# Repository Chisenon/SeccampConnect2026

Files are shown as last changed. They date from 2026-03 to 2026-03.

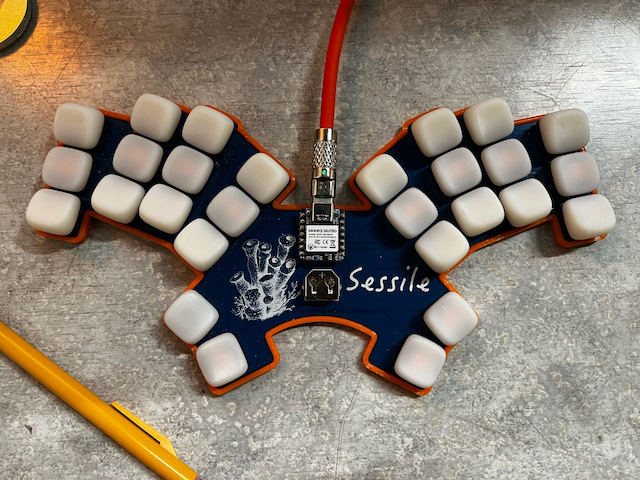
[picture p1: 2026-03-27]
rmk/docs/docs/main/images/sessile.png

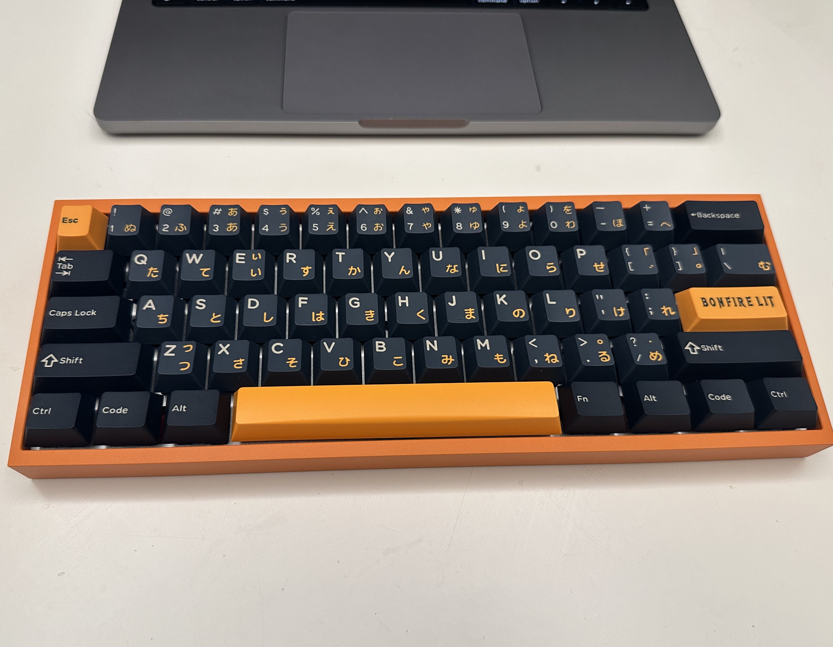
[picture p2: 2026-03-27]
rmk/docs/docs/main/images/rmk_ble_keyboard.jpg

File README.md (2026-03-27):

# SeccampConnect2026
Security Camp Connect 2026

## クイックスタート（開発・書き込み手順）

開発には Docker (ビルド用) とホスト側の `espflash` (書き込み用) を使用します。
アーキテクチャの図解やコマンドの詳細は [WORKFLOW.md](WORKFLOW.md) を参照してください。

### 1. 開発用コンテナの起動
バックグラウンドでビルド用コンテナを待機させます。
```powershell
docker compose up -d
```

### 2. ビルドの実行
起動中のコンテナ内で `cargo build` を実行します。
```powershell
docker compose exec build cargo build --release
```

### 3. デバイスを「書き込みモード」にする（重要！）
ESP32-S3に書き込むには、マイコンを**ダウンロードモード**にする必要があります。

1. マイコン基板上の **BOOTボタン** を押しっぱなしにする
2. PCにUSBケーブルを接続する（接続済みの場合は、BOOTを押しながらRESETボタンを押して離す）
3. BOOTボタンを離す

### 4. ファームウェアの書き込み
割り当てられたCOMポート（例：`COM3`）を確認して書き込みます。
```powershell
# ポート確認
Get-CimInstance Win32_SerialPort | Select-Object Name, Description

# フラッシュ（COM3の場合）
espflash flash .\target\xtensa-esp32s3-none-elf\release\SeccampConnect2026 --port COM3
```

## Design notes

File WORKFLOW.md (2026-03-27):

```mermaid
flowchart TD
    subgraph HOST["Host (Windows)"]
        EDITOR["エディタ <br> src/main.rs を編集"]
        VOLUME[".\\ (プロジェクトルート)"]
        ESPFLASH["espflash<br>(ホスト側)"]
        COM["USB Serial<br>COM3 等"]
        ESP32S3["ESP32S3<br>(XIAO) / BOOTボタンON"]
    end

    subgraph CONTAINER["Docker Container (常時起動)"]
        MOUNT["/work (bind mount)"]
        CARGO["cargo build --release<br>(Xtensa Rust toolchain esp)"]
        ELF["target/xtensa-esp32s3-none-elf <br> /release/SeccampConnect2026"]

        MOUNT --> CARGO
        CARGO --> ELF
    end

    EDITOR -->|"1. ファイル保存"| VOLUME
    VOLUME <-->|"bind mount<br>.:/work"| MOUNT
    ELF -->|"target/ はホストと共有"| VOLUME

    VOLUME -->|"2. docker compose exec build..."| CONTAINER

    VOLUME -->|"4. espflash flash ... --port COM3"| ESPFLASH
    ESPFLASH -->|"USB通信"| COM
    COM -->|"3. ダウンロードモード待機"| ESP32S3
```

## 開発ワークフロー

### 1. 開発環境の起動
DevContainerが言う事聞いてくれないから、
Dockerでビルド用コンテナを手動で起動します。
```powershell
docker compose up -d
```

### 2. ファームウェアのビルド
起動中のコンテナ内でビルドを実行します。
```powershell
docker compose exec build cargo build --release
```

### 3. デバイスを書き込みモード（ダウンロードモード）にする
**BOOTボタンを押しながら**接続してデバイスをPCに認識させる！

### 4. ポートの確認
デバイスが認識されたら、COMポート番号を確認します。
```powershell
Get-CimInstance Win32_SerialPort | Select-Object Name, Description
```

COMX の部分は、実際に認識されたCOMポート番号に置き換えてね！

```
COM3
```

### 5. ファームウェアの書き込み
ホスト側（Windows）から `espflash` を使ってビルドしたELFファイルを書き込みます。
```powershell
espflash flash .\target\xtensa-esp32s3-none-elf\release\SeccampConnect2026 --port COMX
```

---

## コマンド早見表

| ステップ | コマンド |
|---|---|
| コンテナ起動 | `docker compose up -d` |
| コンテナ停止 | `docker compose down` |
| ビルド (release) | `docker compose exec build cargo build --release` |
| ビルドシェルに入る | `docker compose exec build bash` |
| ポート確認 | `Get-CimInstance Win32_SerialPort \| Select-Object Name, Description` |
| 書き込み | `espflash flash .\target\xtensa-esp32s3-none-elf\release\SeccampConnect2026 --port COMX` |

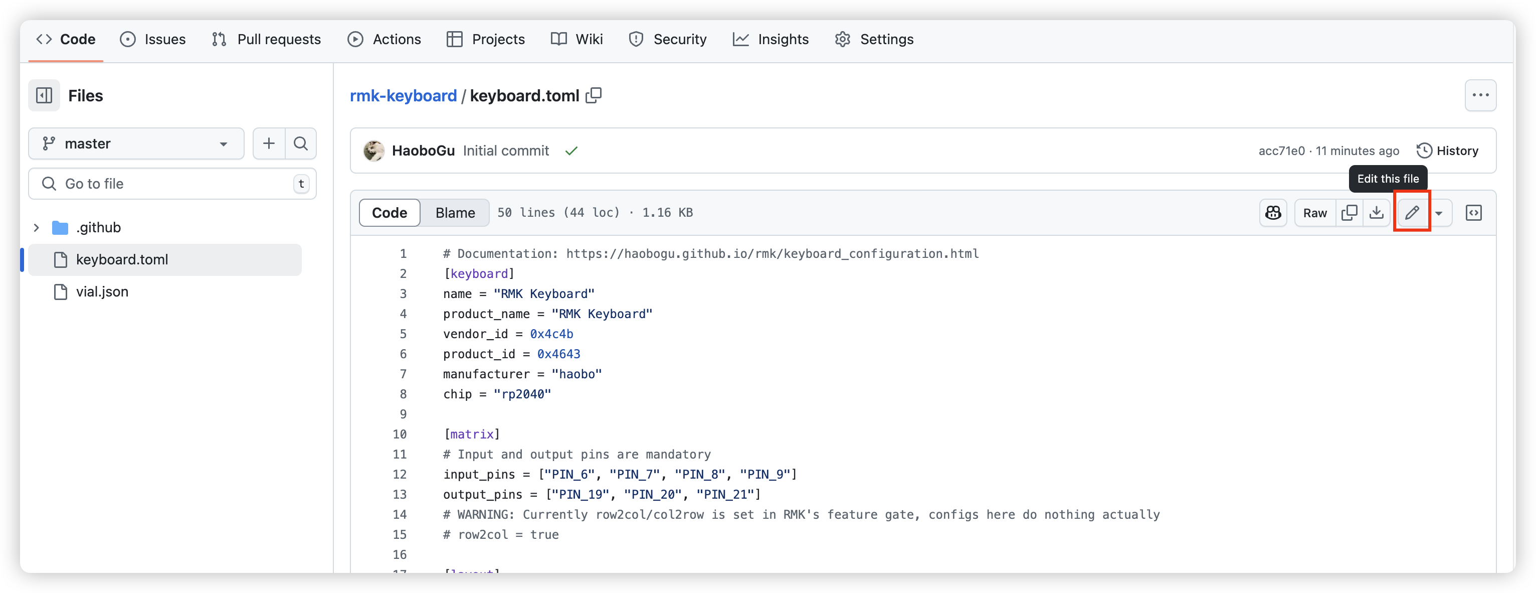
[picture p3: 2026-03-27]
rmk/docs/docs/main/images/edit_config_file.png

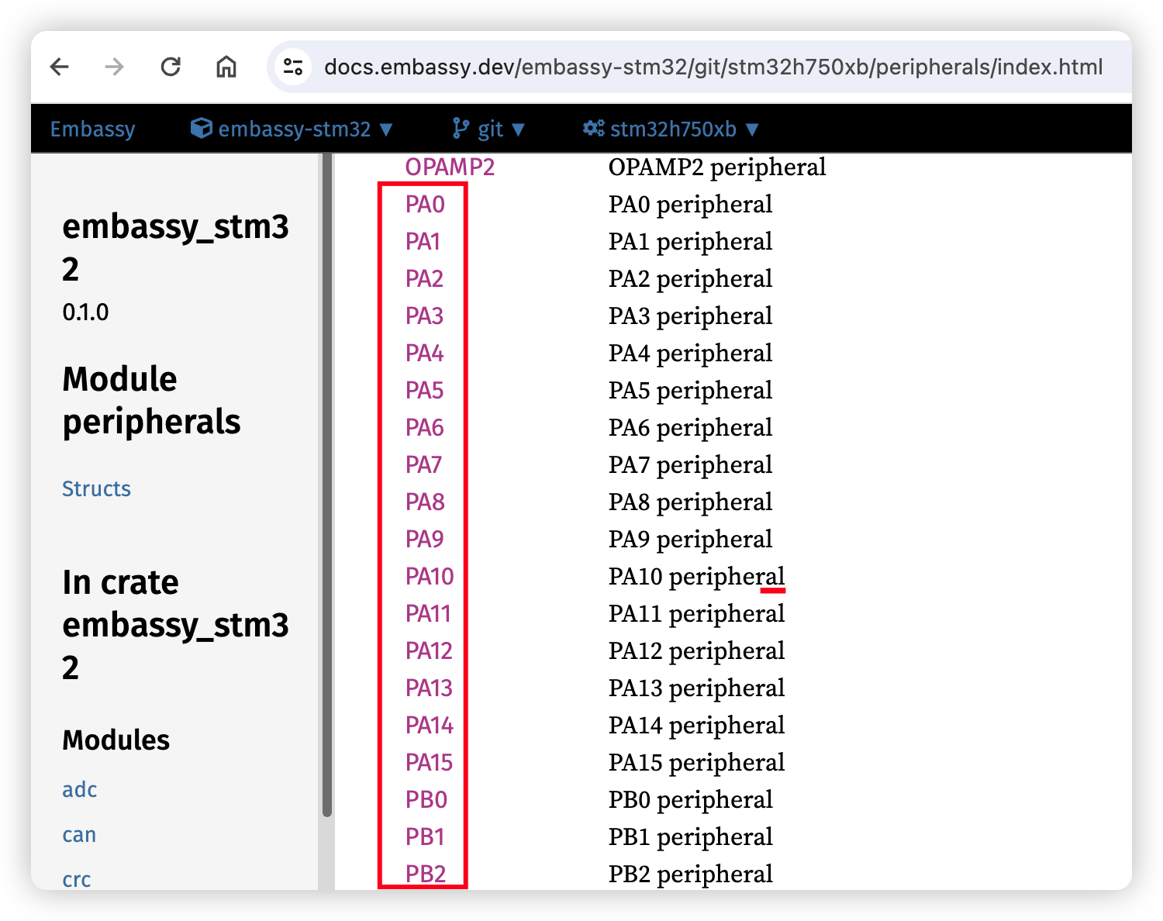
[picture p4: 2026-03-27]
rmk/docs/docs/main/images/gpio_peripheral_name.png

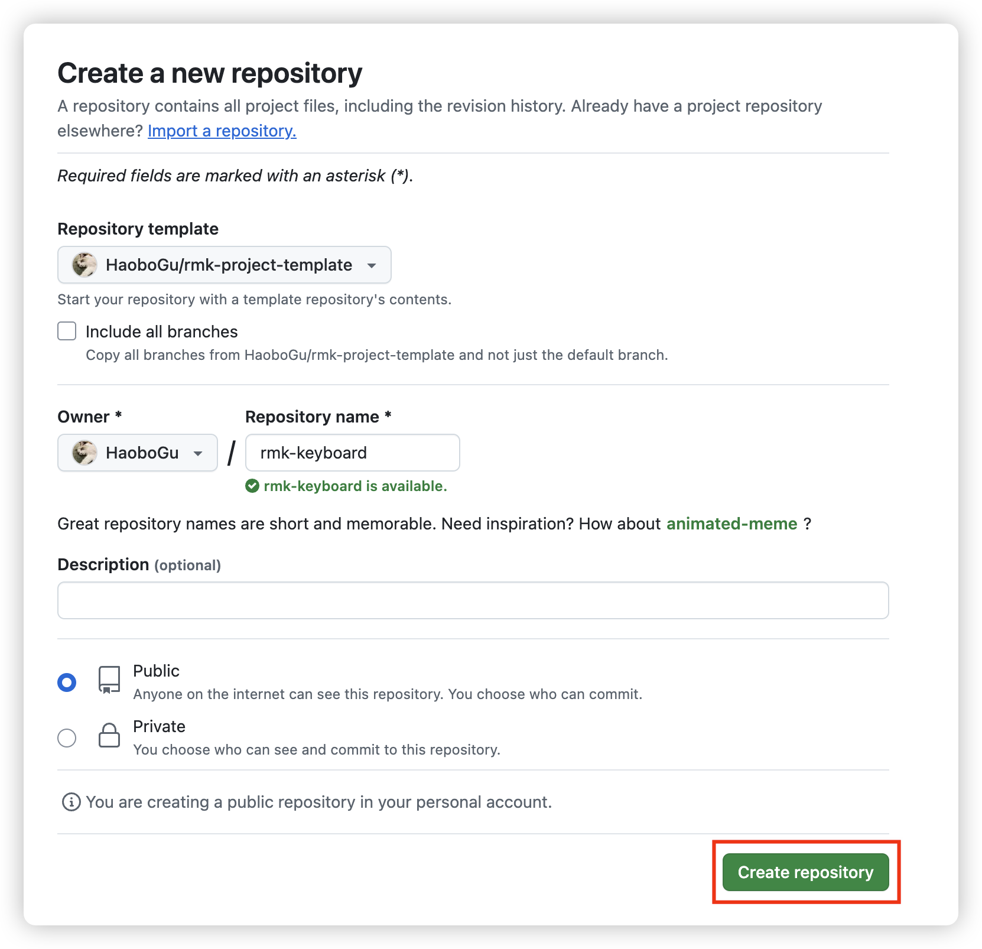
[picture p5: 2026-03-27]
rmk/docs/docs/main/images/create_repository.png

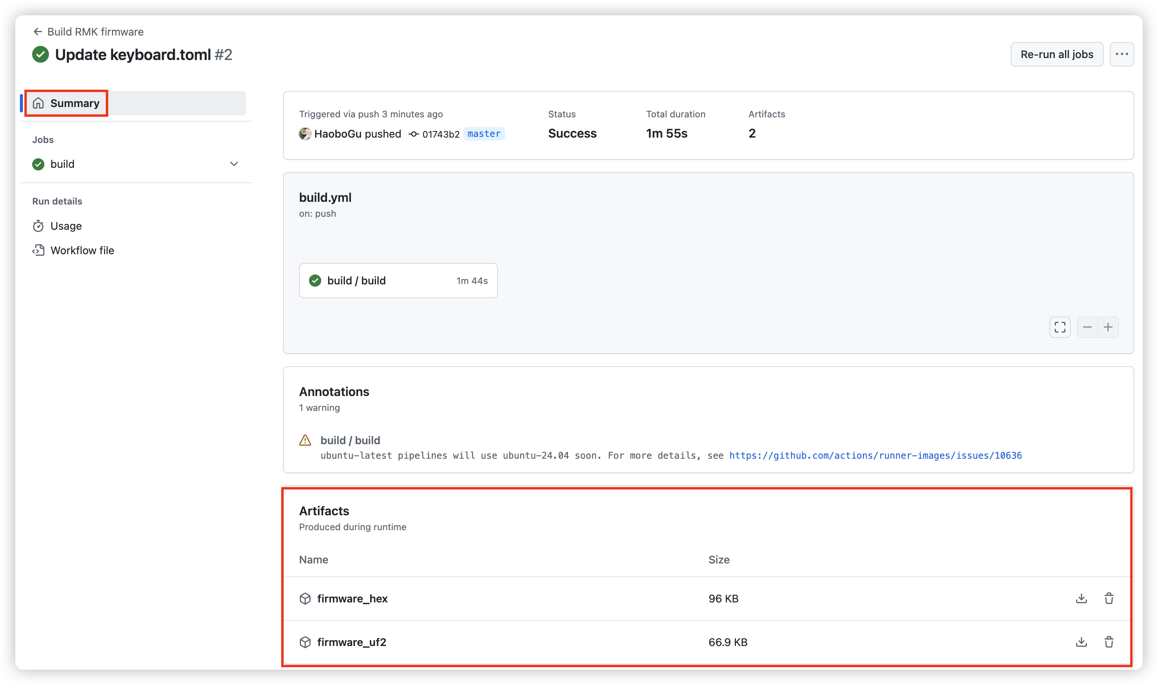
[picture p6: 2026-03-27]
rmk/docs/docs/main/images/artifacts.png

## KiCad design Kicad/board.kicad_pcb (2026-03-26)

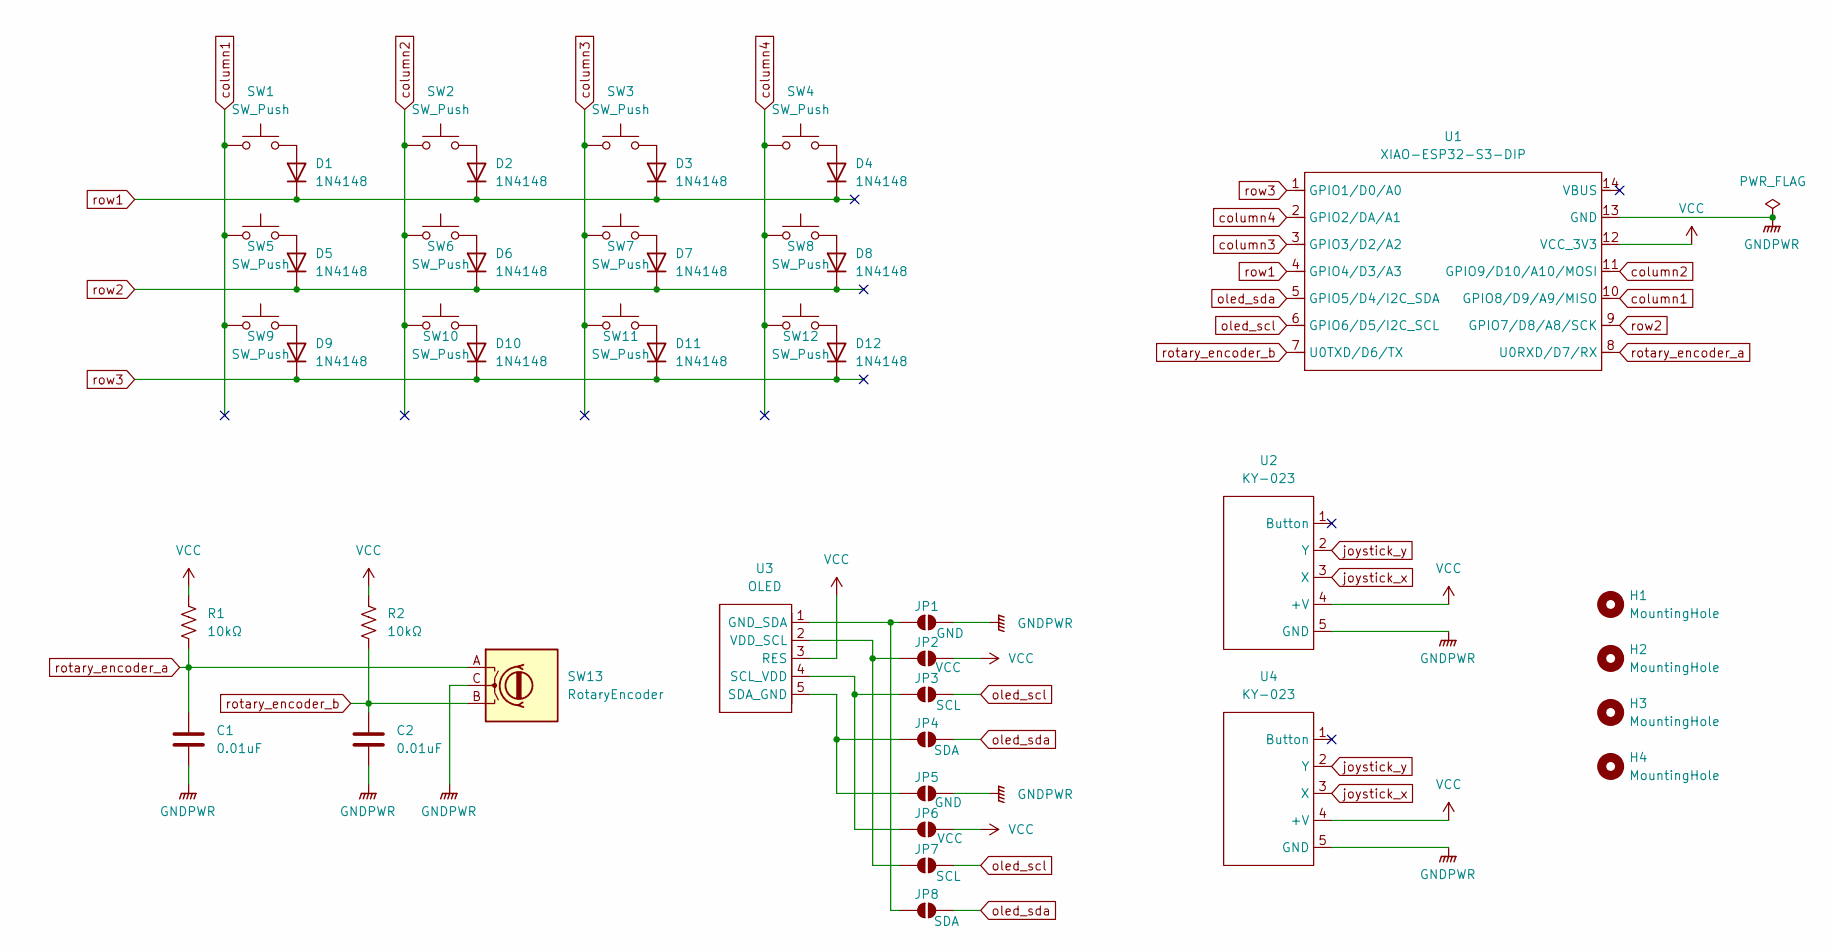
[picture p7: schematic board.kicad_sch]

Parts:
C1, C2: 0.01uF; C_0805_2012_HandSolder_reversible
D1, D2, D3, D4, D5, D6, D7, D8, D9, D10, D11, D12: 1N4148; Diode_THT_reversible
H1, H2, H3, H4: MountingHole; MountingHole_2.7mm
JP1, JP5: GND; SolderJumper-2_P1.3mm_Open_TrianglePad1.0x1.5mm
JP2, JP6: VCC; SolderJumper-2_P1.3mm_Open_TrianglePad1.0x1.5mm
JP3, JP7: SCL; SolderJumper-2_P1.3mm_Open_TrianglePad1.0x1.5mm
JP4, JP8: SDA; SolderJumper-2_P1.3mm_Open_TrianglePad1.0x1.5mm
R1, R2: 10kΩ; R_L6.3mm_D2.5mm_P10.16mm_Horizontal_reversible
SW1, SW2, SW3, SW4, SW5, SW6, SW7, SW8, SW9, SW10, SW11, SW12: SW_Push; Kailh_socket_PG1350_optional_reversible
SW13: RotaryEncoder; RotaryEncoder_Alps_EC12E_Vertical_H20mm
U1: XIAO-ESP32-S3-DIP; XIAO-ESP32S3_reversible
U2, U4: KY-023
U3: OLED; PinSocket_1x05_P2.54mm_Vertical

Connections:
GNDPWR: C1.2, C2.2, JP1.2 (B), JP5.2 (B), SW13.C, U1.13 (GND), U2.5 (GND), U4.5 (GND)
unnamed: D1.2 (A), SW1.2
unnamed: D2.2 (A), SW2.2
unnamed: D3.2 (A), SW3.2
unnamed: D4.2 (A), SW4.2
unnamed: D5.2 (A), SW5.2
unnamed: D6.2 (A), SW6.2
unnamed: D7.2 (A), SW7.2
unnamed: D8.2 (A), SW8.2
unnamed: D9.2 (A), SW9.2
unnamed: D10.2 (A), SW10.2
unnamed: D11.2 (A), SW11.2
unnamed: D12.2 (A), SW12.2
unnamed: JP1.1 (A), JP8.1 (A), U3.1 (GND_SDA)
unnamed: JP2.1 (A), JP7.1 (A), U3.2 (VDD_SCL)
unnamed: JP3.1 (A), JP6.1 (A), U3.4 (SCL_VDD)
unnamed: JP4.1 (A), JP5.1 (A), U3.5 (SDA_GND)
unnamed: U2.2 (Y), U4.2 (Y)
unnamed: U2.3 (X), U4.3 (X)
VCC: JP2.2 (B), JP6.2 (B), R1.1, R2.1, U1.12 (VCC_3V3), U2.4 (+V), U3.3 (RES), U4.4 (+V)
column1: SW1.1, SW5.1, SW9.1, U1.10 (GPIO8/D9/A9/MISO)
column2: SW2.1, SW6.1, SW10.1, U1.11 (GPIO9/D10/A10/MOSI)
column3: SW3.1, SW7.1, SW11.1, U1.3 (GPIO3/D2/A2)
column4: SW4.1, SW8.1, SW12.1, U1.2 (GPIO2/DA/A1)
oled_scl: JP3.2 (B), JP7.2 (B), U1.6 (GPIO6/D5/I2C_SCL)
oled_sda: JP4.2 (B), JP8.2 (B), U1.5 (GPIO5/D4/I2C_SDA)
rotary_encoder_a: C1.1, R1.2, SW13.A, U1.8 (U0RXD/D7/RX)
rotary_encoder_b: C2.1, R2.2, SW13.B, U1.7 (U0TXD/D6/TX)
row1: D1.1 (K), D2.1 (K), D3.1 (K), D4.1 (K), U1.4 (GPIO4/D3/A3)
row2: D5.1 (K), D6.1 (K), D7.1 (K), D8.1 (K), U1.9 (GPIO7/D8/A8/SCK)
row3: D9.1 (K), D10.1 (K), D11.1 (K), D12.1 (K), U1.1 (GPIO1/D0/A0)

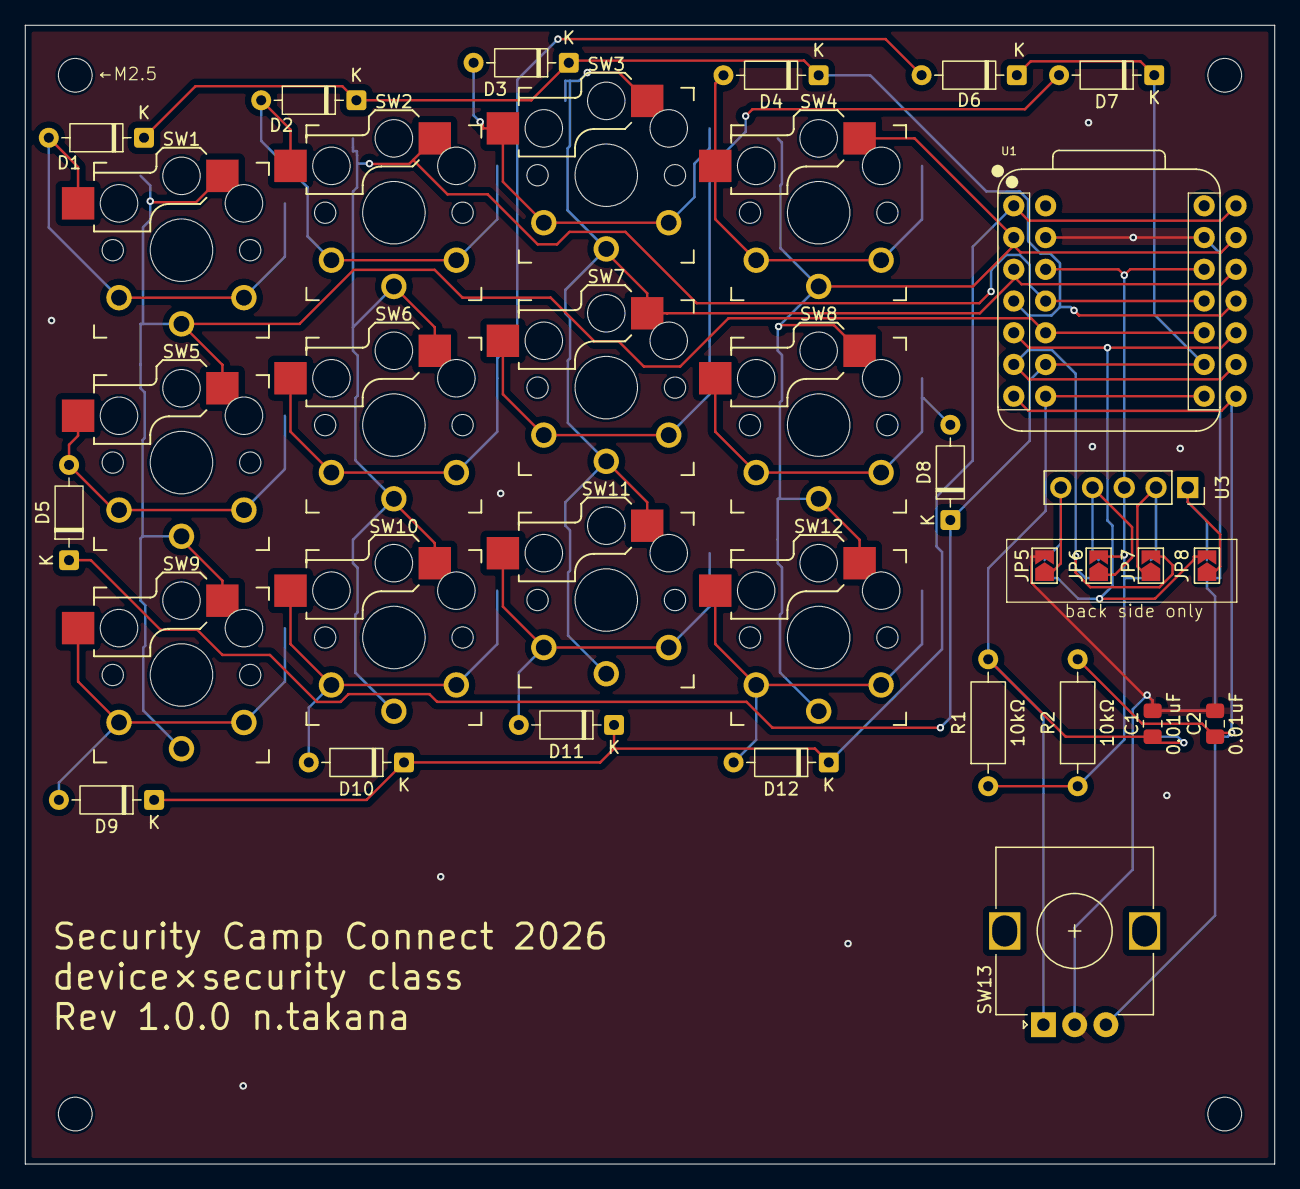
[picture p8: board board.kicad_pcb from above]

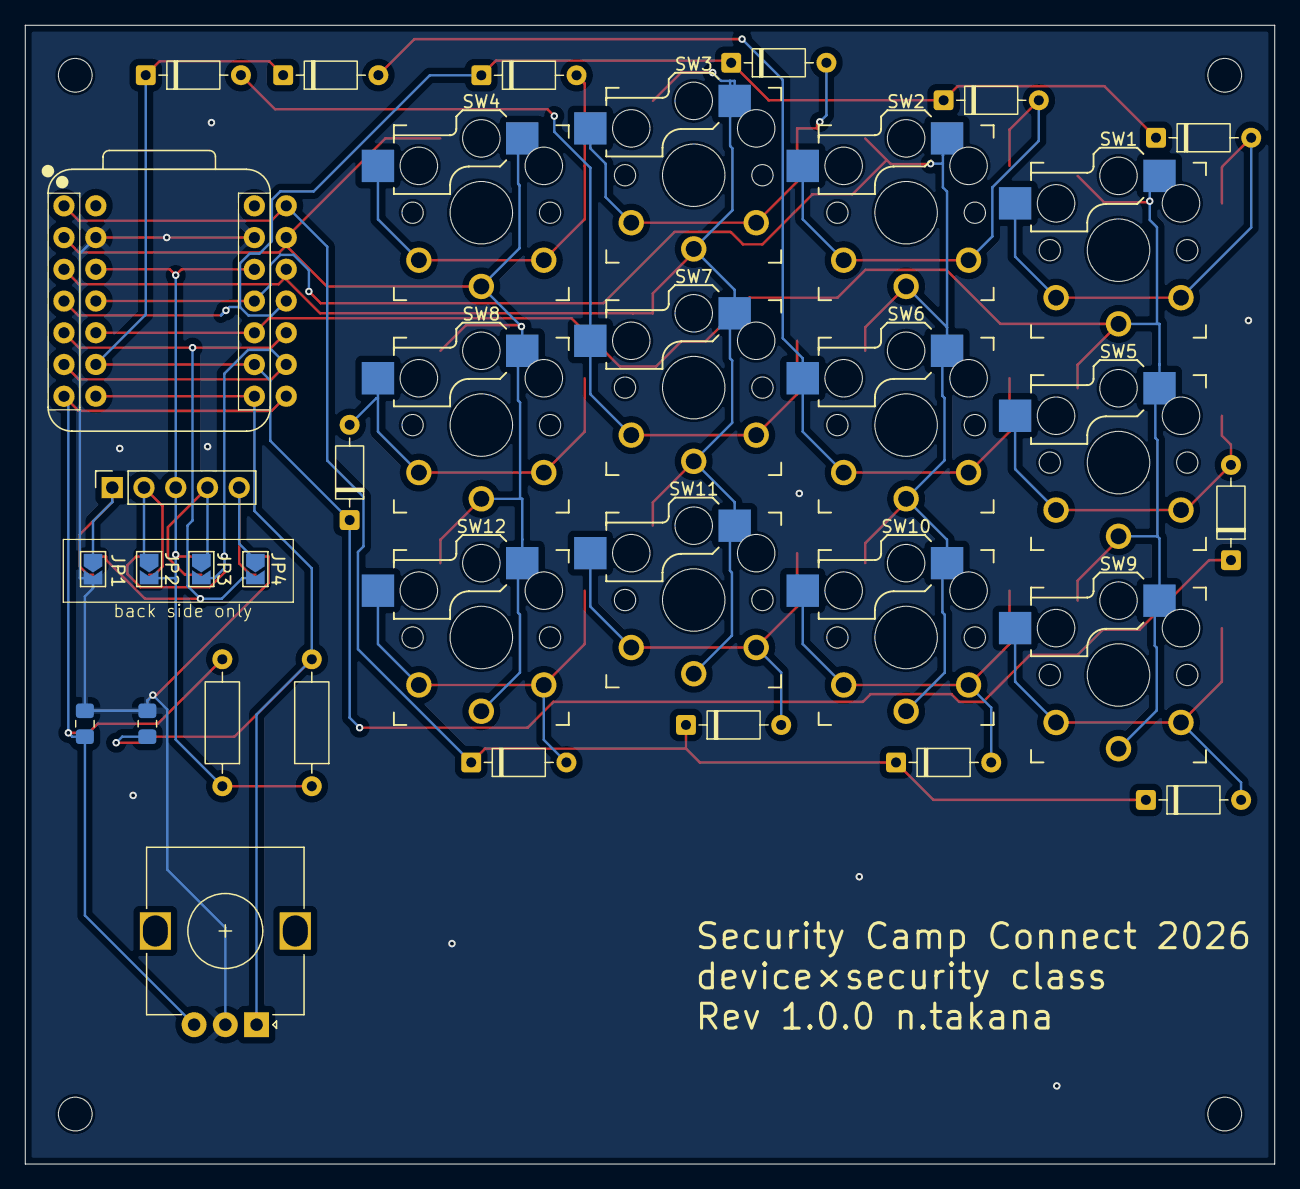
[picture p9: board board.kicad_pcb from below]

Board: 2 copper layers, 100.0 x 91.1 mm, 43 parts (4 on the bottom side), 29 nets.

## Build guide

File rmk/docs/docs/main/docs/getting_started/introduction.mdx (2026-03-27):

# Introduction

RMK is a high-performance and feature-rich keyboard firmware framework, designed for flexibility and ease of customization. RMK leverages the power of Rust and it's great async ecosystem, provides comprehensive and modern functionality across a wide range of microcontrollers. 

## Core Features

- **Broad Microcontroller Support**: ESP32, nRF52, STM32, RP2040/2350, CYW43(Raspberry Pi Pico W), etc.
- **Wired and Wireless Connectivity**: Offers both wired (USB) and wireless (BLE) connections, with optimized low-power performance and multi-profile support.
- **Simple Configuration**: Configure your keyboard easily through a single [TOML](https://toml.io/) file.
- **Advanced Feature Set**: Packed with modern features, including on-the-fly keymap customization, advanced layer management, powerful macros and multi-role key support (e.g., Tap-Hold, TapDance, Morse Key)
- **Split Keyboard Support**: Natively supports both wired and wireless split keyboard.

## Next Steps

import { LinkCard } from '@theme';

<div className="grid grid-cols-1 md:grid-cols-2 gap-5">
<LinkCard
      href="../user_guide/guide_overview"
      title="Tutorial"
      description="A step-by-step tutorial for creating your first RMK keyboard"
/>
<LinkCard
      href="../features"
      title="Features"
      description="All keyboard features that RMK supports"
/>
<LinkCard
      href="../configuration"
      title="Configuration"
      description="Explore how to configure your RMK keyboard"
/>
<LinkCard
      href="https://github.com/HaoboGu/rmk/tree/main/examples"
      title="Examples"
      description="Check the built-in examples for various microcontroller"
/>
</div>

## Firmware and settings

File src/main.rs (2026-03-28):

//! Security Camp Connect 2026
//!
//! [https://www.ipa.go.jp/jinzai/security-camp/2025/connect/device.html](https://www.ipa.go.jp/jinzai/security-camp/2025/connect/device.html)
//!
//! 3x4 prototyping keyboards designed for hands-on practice.
//!
//! # Feature
//! - ESP32S3
//! - Vial support
//! - Low profile with 17 mm pitch
//! - Integrated rotary encoder and 0.91-inch OLED

#![no_std]
#![no_main]

mod keymap;
#[macro_use]
mod macros;
mod oled;
mod vial;

use core::ptr::addr_of_mut;

use bt_hci::controller::ExternalController;
use embassy_executor::Spawner;
use esp_hal::clock::CpuClock;
use esp_hal::gpio::{Input, InputConfig, Level, Output, OutputConfig, Pull};
use esp_hal::otg_fs::Usb;
use esp_hal::otg_fs::asynch::{Config, Driver};
use esp_hal::rng::TrngSource;
use esp_hal::timer::timg::TimerGroup;
use esp_radio::Controller;
use esp_radio::ble::controller::BleConnector;
use esp_storage::FlashStorage;
use rmk::ble::build_ble_stack;
use rmk::channel::EVENT_CHANNEL;
use rmk::config::{
    BehaviorConfig, DeviceConfig, PositionalConfig, RmkConfig, StorageConfig, VialConfig,
};
use rmk::debounce::default_debouncer::DefaultDebouncer;
use rmk::futures::future::join3;
use rmk::input_device::Runnable;
use rmk::input_device::rotary_encoder::DefaultPhase;
use rmk::input_device::rotary_encoder::RotaryEncoder;
use rmk::keyboard::Keyboard;
use rmk::matrix::Matrix;
use rmk::storage::async_flash_wrapper;
use rmk::{HostResources, initialize_encoder_keymap_and_storage, run_devices, run_rmk};
use ssd1306::prelude::DisplayRotation;
use static_cell::StaticCell;
use {esp_alloc as _, esp_backtrace as _};

use crate::keymap::{COL, ROW};
use crate::vial::{VIAL_KEYBOARD_DEF, VIAL_KEYBOARD_ID};

::esp_bootloader_esp_idf::esp_app_desc!();

/// Main function.
///
/// Initialize devices and spawn rmk tasks.
#[allow(clippy::used_underscore_binding)]
#[esp_rtos::main]
async fn main(spawner: Spawner) {
    // Singleton for ble controller.
    static RADIO: StaticCell<Controller<'static>> = StaticCell::new();
    // Endpoint buffer for USB transfer.
    static mut EP_MEMORY: [u8; 1024] = [0; 1024];

    // Initialize the peripherals and bluetooth controller
    esp_println::logger::init_logger_from_env();
    let peripherals = esp_hal::init(esp_hal::Config::default().with_cpu_clock(CpuClock::max()));
    esp_alloc::heap_allocator!(size: 72 * 1024);
    let timg0 = TimerGroup::new(peripherals.TIMG0);
    #[cfg(target_arch = "riscv32")]
    let software_interrupt = SoftwareInterruptControl::new(peripherals.SW_INTERRUPT);
    esp_rtos::start(
        timg0.timer0,
        #[cfg(target_arch = "riscv32")]
        software_interrupt.software_interrupt0,
    );
    let _trng_source = TrngSource::new(peripherals.RNG, peripherals.ADC1);
    let mut rng = esp_hal::rng::Trng::try_new().unwrap();
    let radio = RADIO.init(esp_radio::init().unwrap());
    let bluetooth = peripherals.BT;
    let connector = BleConnector::new(radio, bluetooth, esp_radio::ble::Config::default()).unwrap();
    let controller: ExternalController<_, 20> = ExternalController::new(connector);
    let central_addr = [0x18, 0xe2, 0x21, 0x80, 0xc0, 0xc7];
    let mut host_resources = HostResources::new();
    let stack = build_ble_stack(controller, central_addr, &mut rng, &mut host_resources).await;

    // Initialize USB
    let usb = Usb::new(peripherals.USB0, peripherals.GPIO20, peripherals.GPIO19);
    // Create the driver, from the HAL.
    let config = Config::default();
    let usb_driver = Driver::new(usb, unsafe { &mut *addr_of_mut!(EP_MEMORY) }, config);

    // Initialize the flash
    let flash = FlashStorage::new(peripherals.FLASH);
    let flash = async_flash_wrapper(flash);

    // Spawn oled task
    let display = oled::init_oled(
        peripherals.I2C0,
        peripherals.GPIO5,
        peripherals.GPIO6,
        DisplayRotation::Rotate0,
    )
    .await;
    if let Some(display) = display {
        spawner.spawn(oled::oled_task(display)).unwrap();
    }

    // Initialize the IO pins
    let (row_pins, col_pins) = config_matrix_pins_esp!(peripherals: peripherals, input: [GPIO4, GPIO7, GPIO1], output: [GPIO8, GPIO9, GPIO3, GPIO2]);

    // RMK config
    let vial_config = VialConfig::new(VIAL_KEYBOARD_ID, VIAL_KEYBOARD_DEF, &[(0, 0), (1, 1)]);
    let storage_config = StorageConfig {
        start_addr: 0x3f_0000,
        num_sectors: 16,
        ..Default::default()
    };
    let device_config = DeviceConfig {
        manufacturer: "RMK",
        product_name: "one Keyboard",
        ..Default::default()
    };
    let rmk_config = RmkConfig {
        vial_config,
        storage_config,
        device_config,
        ..Default::default()
    };

    // Initialze keyboard stuffs
    // Initialize the storage and keymap
    let mut default_keymap = keymap::get_default_keymap();
    let mut behavior_config = BehaviorConfig::default();
    let mut encoder_map = keymap::get_default_encoder_map();
    let mut per_key_config = PositionalConfig::default();
    let (keymap, mut storage) = initialize_encoder_keymap_and_storage(
        &mut default_keymap,
        &mut encoder_map,
        flash,
        &storage_config,
        &mut behavior_config,
        &mut per_key_config,
    )
    .await;

    // Initialize the matrix and keyboard
    let debouncer = DefaultDebouncer::new();
    let mut matrix = Matrix::<_, _, _, ROW, COL, true>::new(row_pins, col_pins, debouncer);
    let mut keyboard = Keyboard::new(&keymap); // Initialize the light controller

    // Initialize rotary encoder
    let pin_a = Input::new(peripherals.GPIO43, InputConfig::default());
    let pin_b = Input::new(peripherals.GPIO44, InputConfig::default());
    let mut encoder = RotaryEncoder::with_phase(pin_a, pin_b, DefaultPhase, 0);

    join3(
        run_devices! (
            (matrix, encoder) => EVENT_CHANNEL,
        ),
        keyboard.run(), // Keyboard is special
        run_rmk(&keymap, usb_driver, &stack, &mut storage, rmk_config),
    )
    .await;
}

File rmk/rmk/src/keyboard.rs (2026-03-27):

use core::cell::RefCell;
use core::fmt::Debug;

use embassy_futures::select::{Either, select};
use embassy_futures::yield_now;
#[cfg(feature = "_ble")]
use embassy_sync::signal::Signal;
use embassy_time::{Duration, Instant, Timer, with_deadline};
use heapless::Vec;
use rmk_types::action::{Action, KeyAction, MorseMode};
use rmk_types::keycode::KeyCode;
use rmk_types::led_indicator::LedIndicator;
use rmk_types::modifier::ModifierCombination;
use rmk_types::mouse_button::MouseButtons;
use usbd_hid::descriptor::{MediaKeyboardReport, MouseReport, SystemControlReport};
#[cfg(feature = "controller")]
use {
    crate::channel::{CONTROLLER_CHANNEL, ControllerPub, send_controller_event},
    crate::event::ControllerEvent,
};

use crate::channel::{KEY_EVENT_CHANNEL, KEYBOARD_REPORT_CHANNEL};
use crate::combo::Combo;
use crate::config::Hand;
use crate::descriptor::KeyboardReport;
use crate::event::{KeyPos, KeyboardEvent, KeyboardEventPos};
use crate::fork::{ActiveFork, StateBits};
use crate::hid::Report;
use crate::input_device::Runnable;
use crate::input_device::rotary_encoder::Direction;
use crate::keyboard::held_buffer::{HeldBuffer, HeldKey, KeyState};
use crate::keyboard_macros::MacroOperation;
use crate::keymap::KeyMap;
use crate::morse::{MorsePattern, TAP};
#[cfg(all(feature = "split", feature = "_ble"))]
use crate::split::ble::central::update_activity_time;
use crate::{FORK_MAX_NUM, boot};

pub(crate) mod combo;
pub(crate) mod held_buffer;
pub(crate) mod morse;
pub(crate) mod mouse;
pub(crate) mod oneshot;

const HOLD_BUFFER_SIZE: usize = 16;

// Timestamp of the last key action, the value is the number of seconds since the boot
#[cfg(feature = "_ble")]
pub(crate) static LAST_KEY_TIMESTAMP: Signal<crate::RawMutex, u32> = Signal::new();

/// Led states for the keyboard hid report (its value is received by by the light service in a hid report)
/// LedIndicator type would be nicer, but that does not have const expr constructor
pub(crate) static LOCK_LED_STATES: core::sync::atomic::AtomicU8 = core::sync::atomic::AtomicU8::new(0u8);

/// State machine for one shot keys
#[derive(Default)]
enum OneShotState<T> {
    /// First one shot key press
    Initial(T),
    /// One shot key was released before any other key, normal one shot behavior
    Single(T),
    /// Another key was pressed before one shot key was released, treat as a normal modifier/layer
    Held(T),
    /// One shot inactive
    #[default]
    None,
}

impl<T> OneShotState<T> {
    /// Get the current one shot value if any
    pub fn value(&self) -> Option<&T> {
        match self {
            OneShotState::Initial(v) | OneShotState::Single(v) | OneShotState::Held(v) => Some(v),
            OneShotState::None => None,
        }
    }
}

/// State machine for Caps Word
#[derive(Debug, Default)]
enum CapsWordState {
    /// Caps Word is activated (but may have timed out thus becoming inactive)
    Activated {
        /// Time since last key press
        timer: Instant,
        /// Whether the current key should be shifted
        shift_current: bool,
    },
    /// Caps Word is deactivated
    #[default]
    Deactivated,
}

impl CapsWordState {
    /// Caps Word timeout duration
    const TIMEOUT: Duration = Duration::from_secs(5);

    /// Activate Caps Word
    fn activate(&mut self) {
        *self = CapsWordState::Activated {
            timer: Instant::now(),
            shift_current: false,
        };
    }

    /// Deactivate Caps Word
    fn deactivate(&mut self) {
        *self = CapsWordState::Deactivated;
    }

    /// Toggle Caps Word
    fn toggle(&mut self) {
        match self {
            CapsWordState::Activated { .. } => self.deactivate(),
            CapsWordState::Deactivated => self.activate(),
        }
    }

    /// Return whether Caps Word is active (and has not timed out)
    fn is_active(&self) -> bool {
        if let CapsWordState::Activated { timer, .. } = self {
            timer.elapsed() < Self::TIMEOUT
        } else {
            false
        }
    }

    /// Return whether the current key pressed is to be shifted
    fn is_shift_current(&self) -> bool {
        if let CapsWordState::Activated { shift_current, .. } = self {
            *shift_current
        } else {
            false
        }
    }

    /// Check whether to shift the given key, and update the state accordingly
    ///
    /// Note that this function does not check the CapsWord key itself.
    fn check(&mut self, key: KeyCode) {
        if let CapsWordState::Activated { timer, shift_current } = self {
            if key.is_caps_word_continue_key() && timer.elapsed() < Self::TIMEOUT {
                *timer = Instant::now();
                *shift_current = key.is_caps_word_shifted_key();
            } else {
                self.deactivate();
            }
        }
    }
}
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

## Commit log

2026-03-26 [fix] update Dockerfile and docker-compose.yml for non-root user support; enhance build scripts
    [main.rs]
2026-03-27 [fix] update OLED display task to handle optional display initialization; improve display management
    [main.rs, oled.rs]
2026-03-28 [Update] product name in DeviceConfig from "my Keyboard" to "one Keyboard"
